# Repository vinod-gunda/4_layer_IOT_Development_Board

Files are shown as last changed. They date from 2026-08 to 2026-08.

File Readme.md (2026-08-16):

# 4-Layer ESP32-C3 Development Board

A custom **4-layer ESP32-C3 development board** designed from scratch using **KiCad 10** as part of my embedded systems and PCB design learning.

## Key Features

- ESP32-C3 based controller
- USB-C, USB-UART, Li-Po charging and power management
- SD Card, Flash Memory and sensor interfaces
- 4-layer PCB with power and GND distribution

## PCB Design Skills

- Custom schematic symbol design
- Custom footprint design
- Custom logo-to-footprint conversion
- Hierarchical schematic design
- PCB layout, routing and DRC verification

## Tools & Technology

- **KiCad 10**
- **ESP32-C3**
- **4-Layer PCB**

## Repository Contents

- KiCad schematic files
- PCB layout files
- Custom symbols and footprints
- Project images

## Purpose

This project was developed for **learning, prototyping, and improving practical PCB design skills**.

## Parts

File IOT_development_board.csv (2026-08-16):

Reference | Qty | Value | DNP | Exclude from BOM | Exclude from Board | Footprint | Datasheet
C1 | 1 | 0.1u |  |  |  | Capacitor_SMD:C_0805_2012Metric
C2,C5,C8,C10,C13,C14,C15,C16,C18,C20,C21 | 11 | 0.1uF |  |  |  | Capacitor_SMD:C_0805_2012Metric
C3,C4 | 2 | 10uF |  |  |  | TANTALUM-SMD-10UF-20V-20__1206:CT1206
C6 | 1 | 1u |  |  |  | Capacitor_SMD:C_0805_2012Metric
C7,C12 | 2 | 10uf |  |  |  | TANTALUM-SMD-10UF-20V-20__1206:CT1206
C9 | 1 | 4.7uF |  |  |  | TANTALUM-SMD-10UF-20V-20__1206:CT1206
C11,C19,C22 | 3 | 1uF |  |  |  | Capacitor_SMD:C_0805_2012Metric
C17 | 1 | 10nF |  |  |  | Capacitor_SMD:C_0805_2012Metric
D1,D5 | 2 | LTST-C170GKT |  |  |  | LTST-C170GKT:LED_LTST-C170GKT
D2,D4,D6 | 3 | LTST-C170KRKT |  |  |  | LTST-C170KRKT:DIOC200X125X110
D3 | 1 | LTST-C170TBKT |  |  |  | LTST-C170TBKT:DIOC200X125X110
F1 | 1 | 0ZCH0110AF2E |  |  |  | 0ZCH0110AF2E:FUSC3225X100N
J1 | 1 | SS-52400-003 |  |  |  | C_TYPE:BELFUSE_SS-52400-003
J2 | 1 | B2B-PH-SM4-TB |  |  |  | B2B-PH-SM4-TB:JST_B2B-PH-SM4-TB
J3 | 1 | GSD090012SEU |  |  |  | GSD090012SEU:AMPHENOL_GSD090012SEU
J4 | 1 | Conn_01x04_Pin |  |  |  | Connector_PinHeader_2.54mm:PinHeader_1x04_P2.54mm_Vertical
J5 | 1 | Conn_01x05_Pin |  |  |  | Connector_PinHeader_2.54mm:PinHeader_1x05_P2.54mm_Vertical
MK1 | 1 | CMC-5042PF-AC |  |  |  | CMC-5042PF-AC:CUI_CMC-5042PF-AC
Q1 | 1 | TEMT6000X01 |  |  |  | TEMT6000X01:TRANS_TEMT6000X01
Q2,Q3 | 2 | BC817 |  |  |  | Package_TO_SOT_SMD:SOT-23 | https://www.onsemi.com/pub/Collateral/BC818-D.pdf
R1,R2,R19,R23,R30,R32,R33,R34 | 8 | 10K |  |  |  | Resistor_SMD:R_0805_2012Metric
R3,R4 | 2 | 5.1K |  |  |  | Resistor_SMD:R_0805_2012Metric
R5,R26,R28 | 3 | 2K |  |  |  | Resistor_SMD:R_0805_2012Metric
R6 | 1 | 20K |  |  |  | Resistor_SMD:R_0805_2012Metric
R7,R8,R9,R10,R14,R15 | 6 | 470 |  |  |  | Resistor_SMD:R_0805_2012Metric
R11 | 1 | 1K |  |  |  | Resistor_SMD:R_0805_2012Metric
R12 | 1 | 22.1K |  |  |  | Resistor_SMD:R_0805_2012Metric
R13 | 1 | 47.5K |  |  |  | Resistor_SMD:R_0805_2012Metric
R16,R20,R21,R22 | 4 | 50 |  |  |  | Resistor_SMD:R_0805_2012Metric
R24,R25 | 2 | 4.7K |  |  |  | Resistor_SMD:R_0805_2012Metric
R27,R29 | 2 | 1M |  |  |  | Resistor_SMD:R_0805_2012Metric
R31 | 1 | 100K |  |  |  | Resistor_SMD:R_0805_2012Metric
S1 | 1 | BOOT |  |  |  | USLPT2819DT2TR:SW_USLPT2819DT2TR
S2 | 1 | RESET |  |  |  | USLPT2819DT2TR:SW_USLPT2819DT2TR
TP1 | 1 | MOSI |  |  |  | TestPoint:TestPoint_Pad_D1.0mm
TP2 | 1 | MISO |  |  |  | TestPoint:TestPoint_Pad_D1.0mm
TP3 | 1 | SCLK |  |  |  | TestPoint:TestPoint_Pad_D1.0mm
TP4 | 1 | CS_SD |  |  |  | TestPoint:TestPoint_Pad_D1.0mm
TP5 | 1 | CS |  |  |  | TestPoint:TestPoint_Pad_D1.0mm
U1 | 1 | MCP73871 |  |  |  | Package_DFN_QFN:QFN-20-1EP_4x4mm_P0.5mm_EP2.5x2.5mm | http://www.mouser.com/ds/2/268/22090a-52174.pdf
U2 | 1 | BME280 |  |  |  | BME280:PSON65P250X250X100-8N
U3 | 1 | ESP32-C3-WROOM-02-H4 |  |  |  | ESP32-C3-WROOM-02-H4:MODULE_ESP32-C3-WROOM-02-H4
U4 | 1 | CP2102N-A02-GQFN20R |  |  |  | CP2102N-A02-GQFN20R:SILABS_CP2102N-A02-GQFN20R
U5 | 1 | USBLC6-2SC6 |  |  |  | Package_TO_SOT_SMD:SOT-23-6 | https://www.st.com/resource/en/datasheet/usblc6-2.pdf
U6 | 1 | W25Q32JVSSIQ |  |  |  | W25Q32JVSSIQ:SOIC127P790X216-8N
U7 | 1 | MAX4466EXK |  |  |  | MAX4466EXK:SOT65P210X110-5N
VR1 | 1 | LM1117MPX-3.3 |  |  |  | LM1117MPX-3.3:VREG_LM1117MPX-3.3

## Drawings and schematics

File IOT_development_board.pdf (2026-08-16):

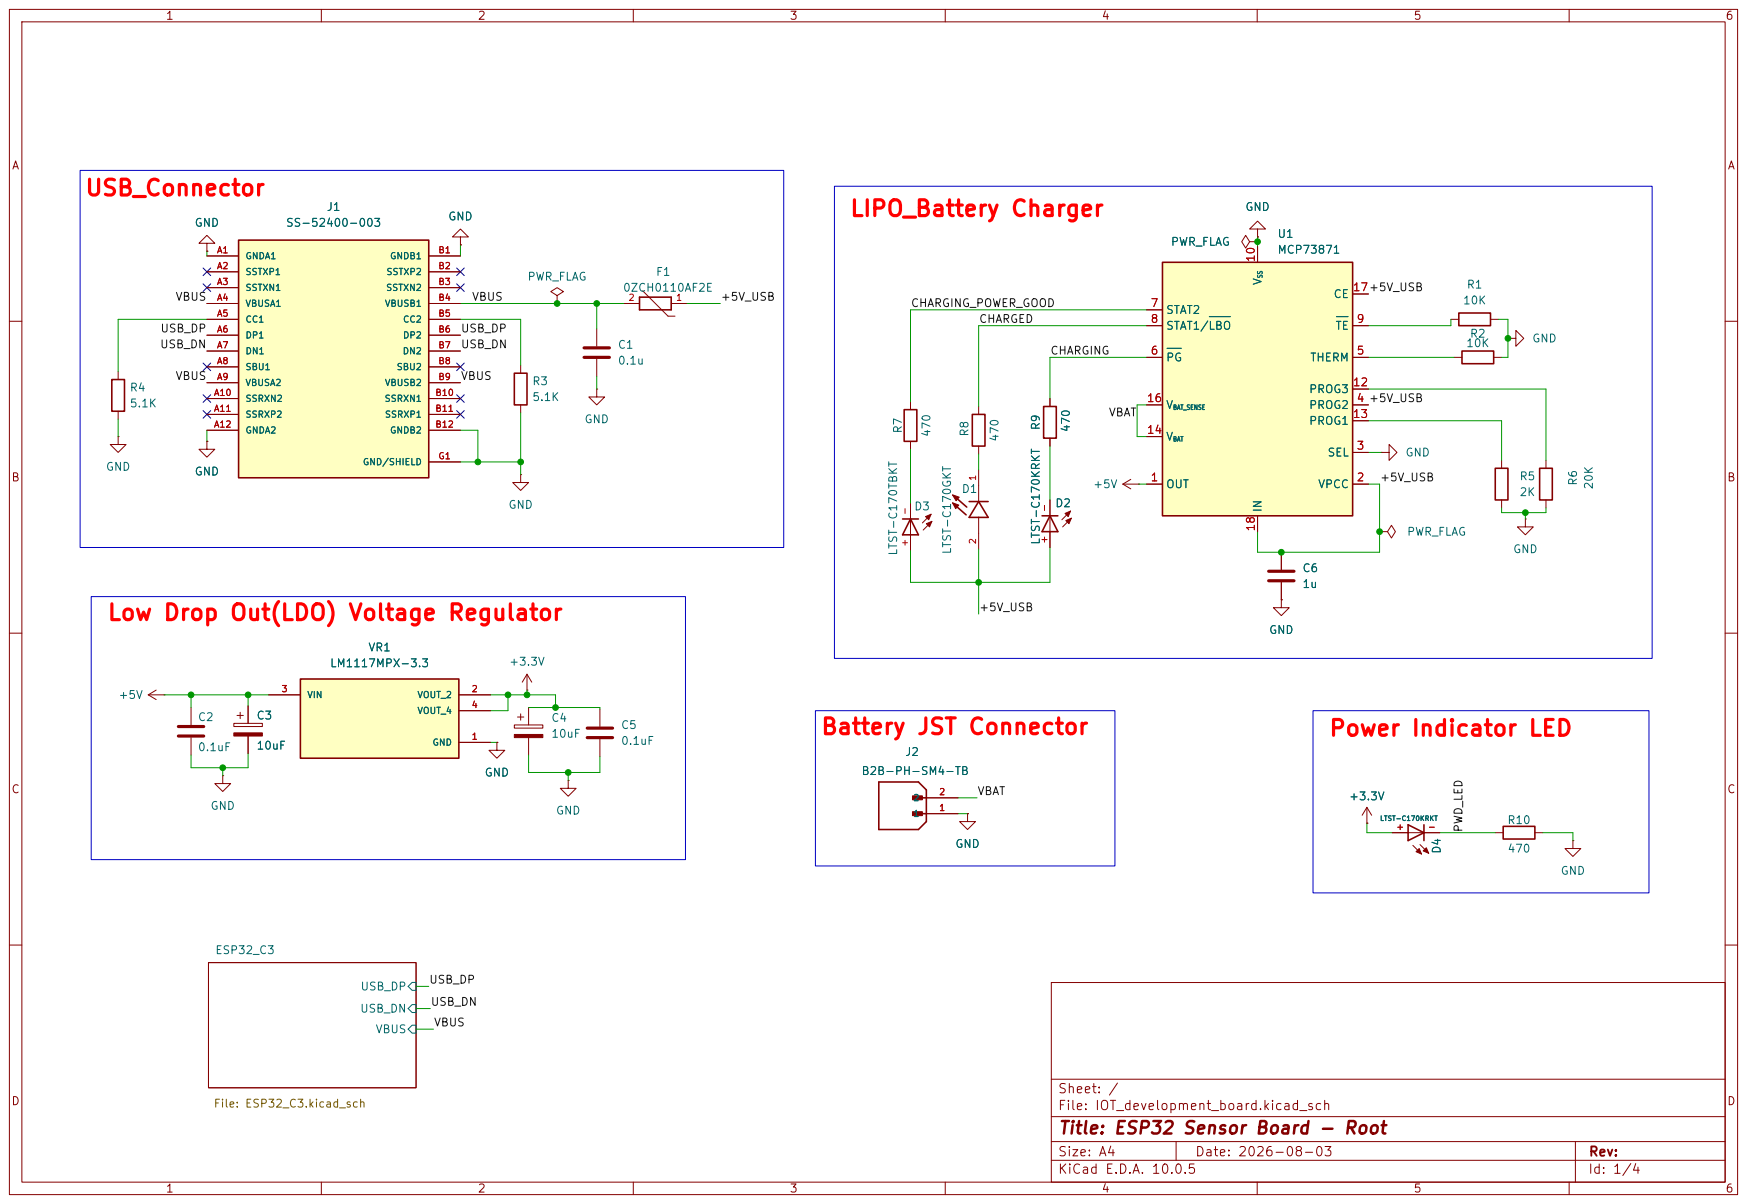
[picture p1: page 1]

Low Drop Out(LDO) Voltage Regulator

Sheet: /
File: IOT_development_board.kicad_sch
Title: ESP32 Sensor Board - Root

Size: A4 | Rev:
KiCad E.D.A. 10.0.5 | Id: 1/4

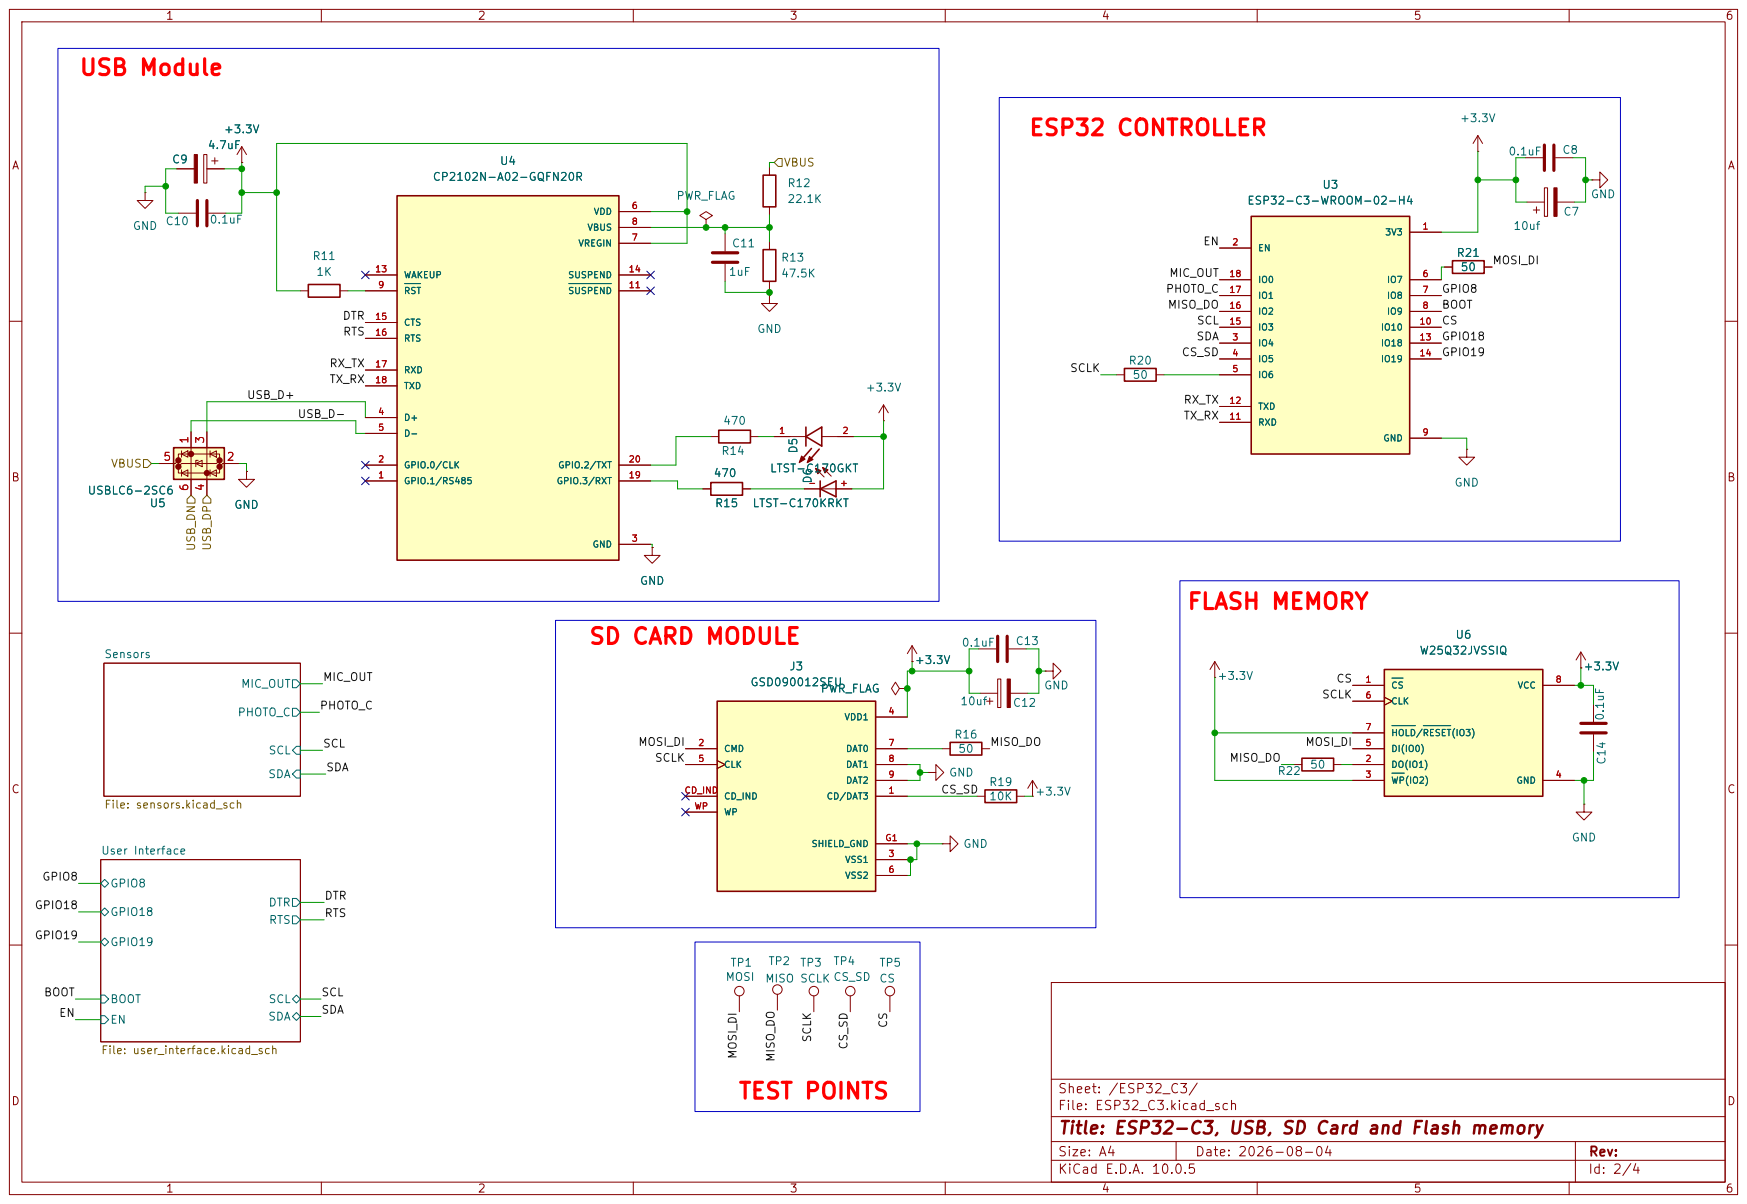
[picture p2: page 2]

SCL SDA User Interface

Sheet: /ESP32_C3/
File: ESP32_C3.kicad_sch
Title: ESP32-C3, USB, SD Card and Flash memory

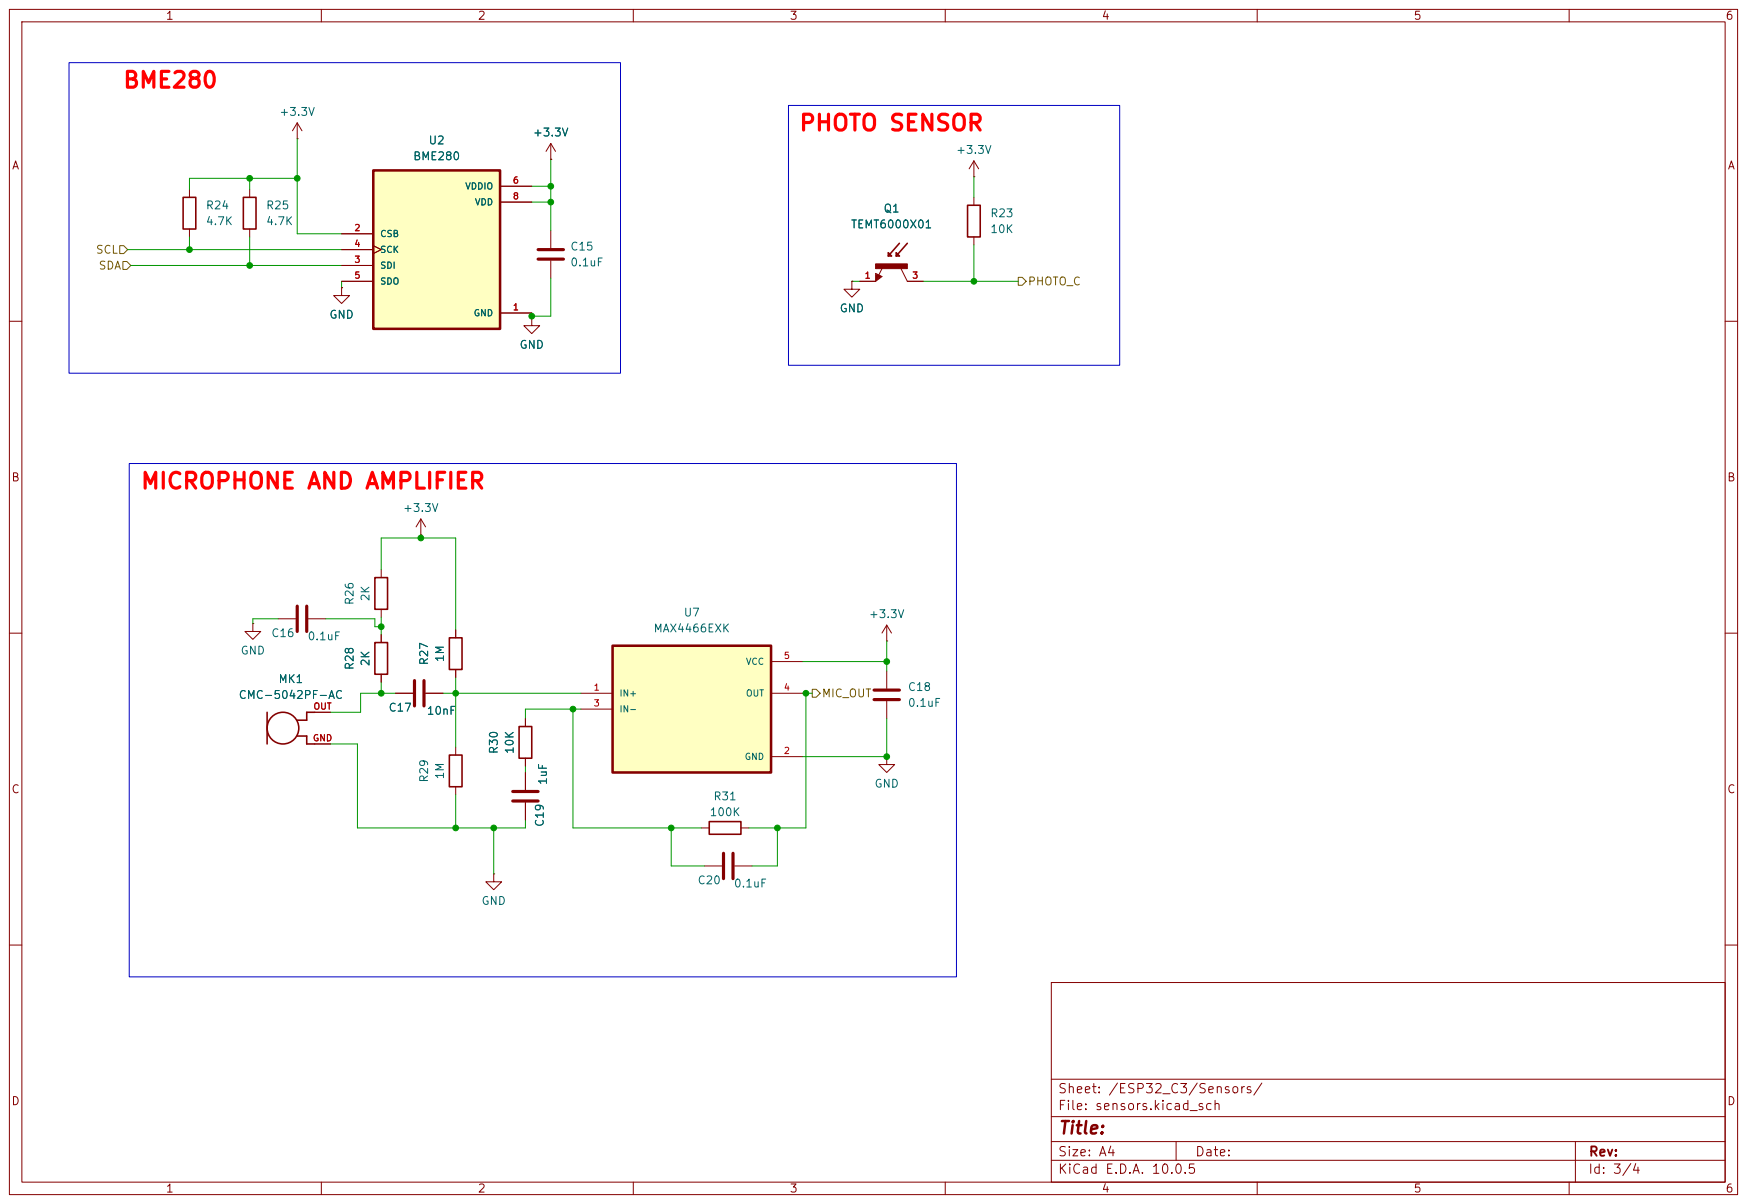
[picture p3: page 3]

GND OUT MK1 CMC-5042PF-AC R26 2K

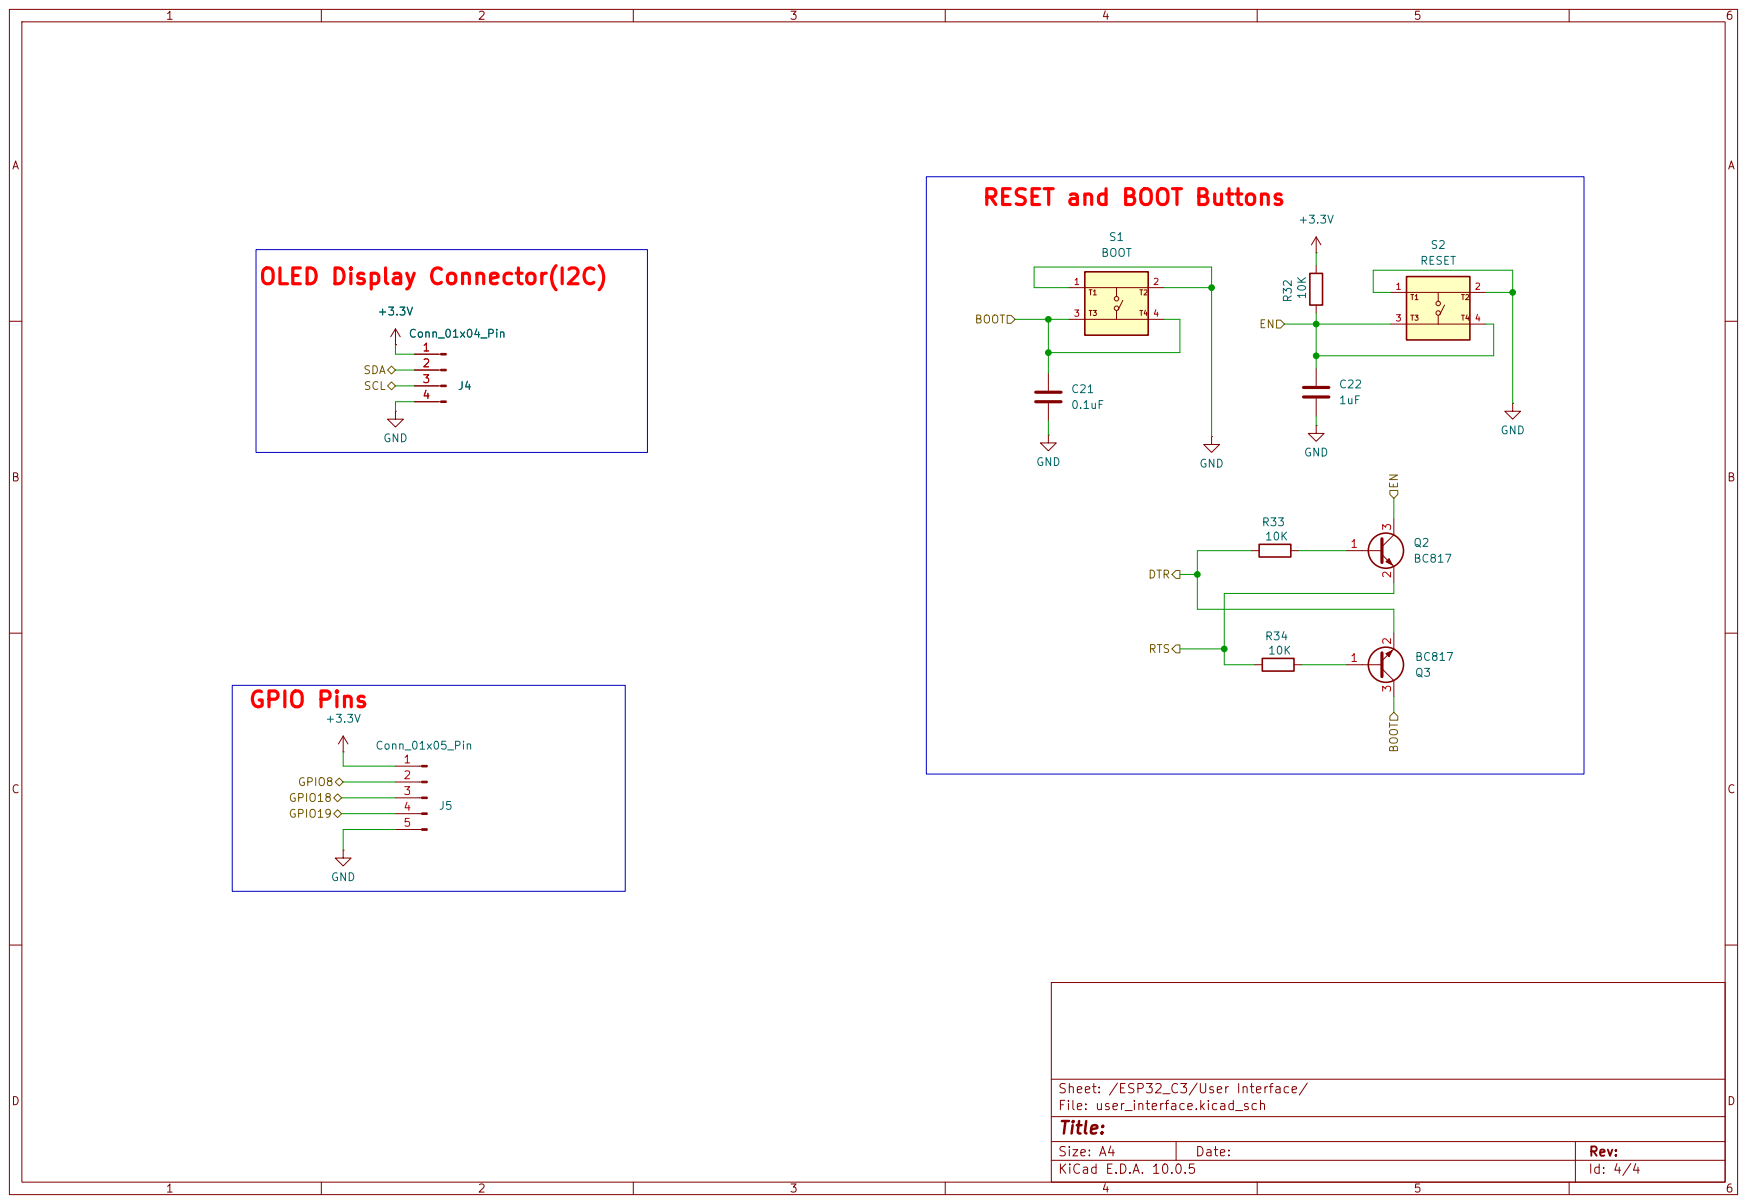
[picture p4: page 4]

EN RESET and BOOT Buttons

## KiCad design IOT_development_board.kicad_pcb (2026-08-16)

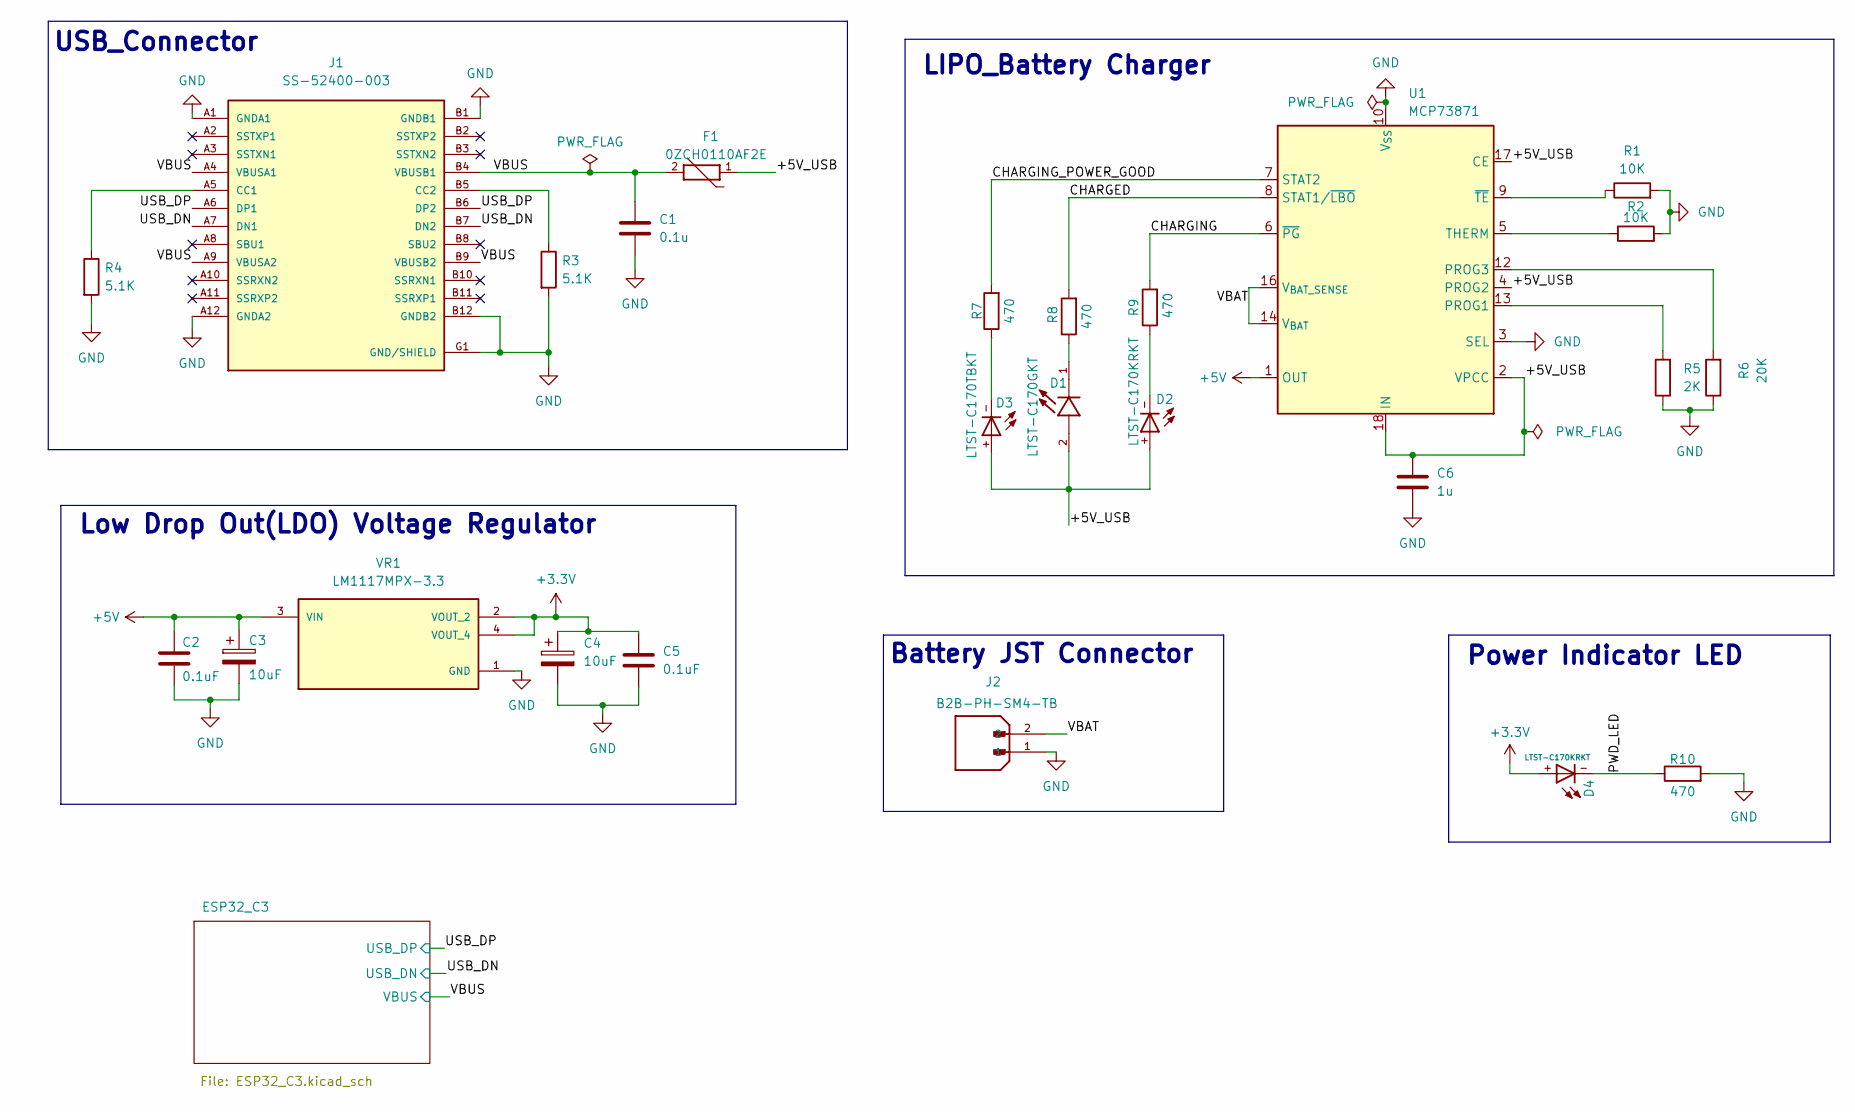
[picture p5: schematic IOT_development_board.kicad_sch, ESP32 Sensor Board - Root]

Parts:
C1: 0.1u; C_0805_2012Metric
C2, C5: 0.1uF; C_0805_2012Metric
C3, C4: 10uF; CT1206
C6: 1u; C_0805_2012Metric
D1: LTST-C170GKT; LED_LTST-C170GKT; PARTREV I
D2, D4: LTST-C170KRKT; DIOC200X125X110
D3: LTST-C170TBKT; DIOC200X125X110
F1: 0ZCH0110AF2E; FUSC3225X100N; PARTREV Apr2023
J1: SS-52400-003; BELFUSE_SS-52400-003; PARTREV A0
J2: B2B-PH-SM4-TB; JST_B2B-PH-SM4-TB; PARTREV N/A
R1, R2: 10K; R_0805_2012Metric
R3, R4: 5.1K; R_0805_2012Metric
R5: 2K; R_0805_2012Metric
R6: 20K; R_0805_2012Metric
R7, R8, R9, R10: 470; R_0805_2012Metric
U1: MCP73871; QFN-20-1EP_4x4mm_P0.5mm_EP2.5x2.5mm
VR1: LM1117MPX-3.3; VREG_LM1117MPX-3.3; PARTREV O

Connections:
+3.3V: C4.1, C5.1, D4.+, VR1.2 (VOUT_2), VR1.4 (VOUT_4); also elsewhere on the board
+5V: C2.1, C3.1, U1.1 (OUT), U1.20 (OUT), VR1.3 (VIN)
/+5V_USB: C6.1, D1.2, D2.+, D3.+, F1.1, U1.2 (VPCC), U1.4 (PROG2), U1.17 (CE), U1.18 (IN), U1.19 (IN)
/CHARGED: R8.2, U1.8 (STAT1/~LBO)
/CHARGING: R9.2, U1.6 (~PG)
/CHARGING_POWER_GOOD: R7.2, U1.7 (STAT2)
/PWD_LED: D4.-, R10.1
/USB_DN: J1.A7 (DN1), J1.B7 (DN2); also elsewhere on the board
/USB_DP: J1.A6 (DP1), J1.B6 (DP2); also elsewhere on the board
/VBAT: J2.2, U1.14 (V_{BAT}), U1.15 (V_{BAT}), U1.16 (V_{BAT_SENSE})
/VBUS: C1.1, F1.2, J1.A4 (VBUSA1), J1.A9 (VBUSA2), J1.B4 (VBUSB1), J1.B9 (VBUSB2); also elsewhere on the board
GND: C1.2, C2.2, C3.2, C4.2, C5.2, C6.2, J1.A1 (GNDA1), J1.A12 (GNDA2), J1.B1 (GNDB1), J1.B12 (GNDB2), J1.G1 (GND/SHIELD), J1.G2 (GND/SHIELD), J1.G3 (GND/SHIELD), J1.G4 (GND/SHIELD), J1.S1 (GND/SHIELD), J1.S2 (GND/SHIELD), J1.S3 (GND/SHIELD), J1.S4 (GND/SHIELD), J2.1, R1.2, R2.2, R3.2, R4.2, R5.1, R6.1, R10.2, U1.3 (SEL), U1.10 (V_{SS}), U1.11 (V_{SS}), U1.21 (V_{SS}), VR1.1 (GND); also elsewhere on the board
unnamed: D1.1, R8.1
unnamed: D2.-, R9.1
unnamed: D3.-, R7.1
unnamed: J1.A5 (CC1), R4.1
unnamed: J1.B5 (CC2), R3.1
unnamed: R5.2, U1.13 (PROG1)
unnamed: R6.2, U1.12 (PROG3)
unnamed: R2.1, U1.5 (THERM)
unnamed: R1.1, U1.9 (~TE)

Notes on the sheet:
LIPO_Battery Charger
Battery JST Connector
Power Indicator LED
Low Drop Out(LDO) Voltage Regulator
USB_Connector

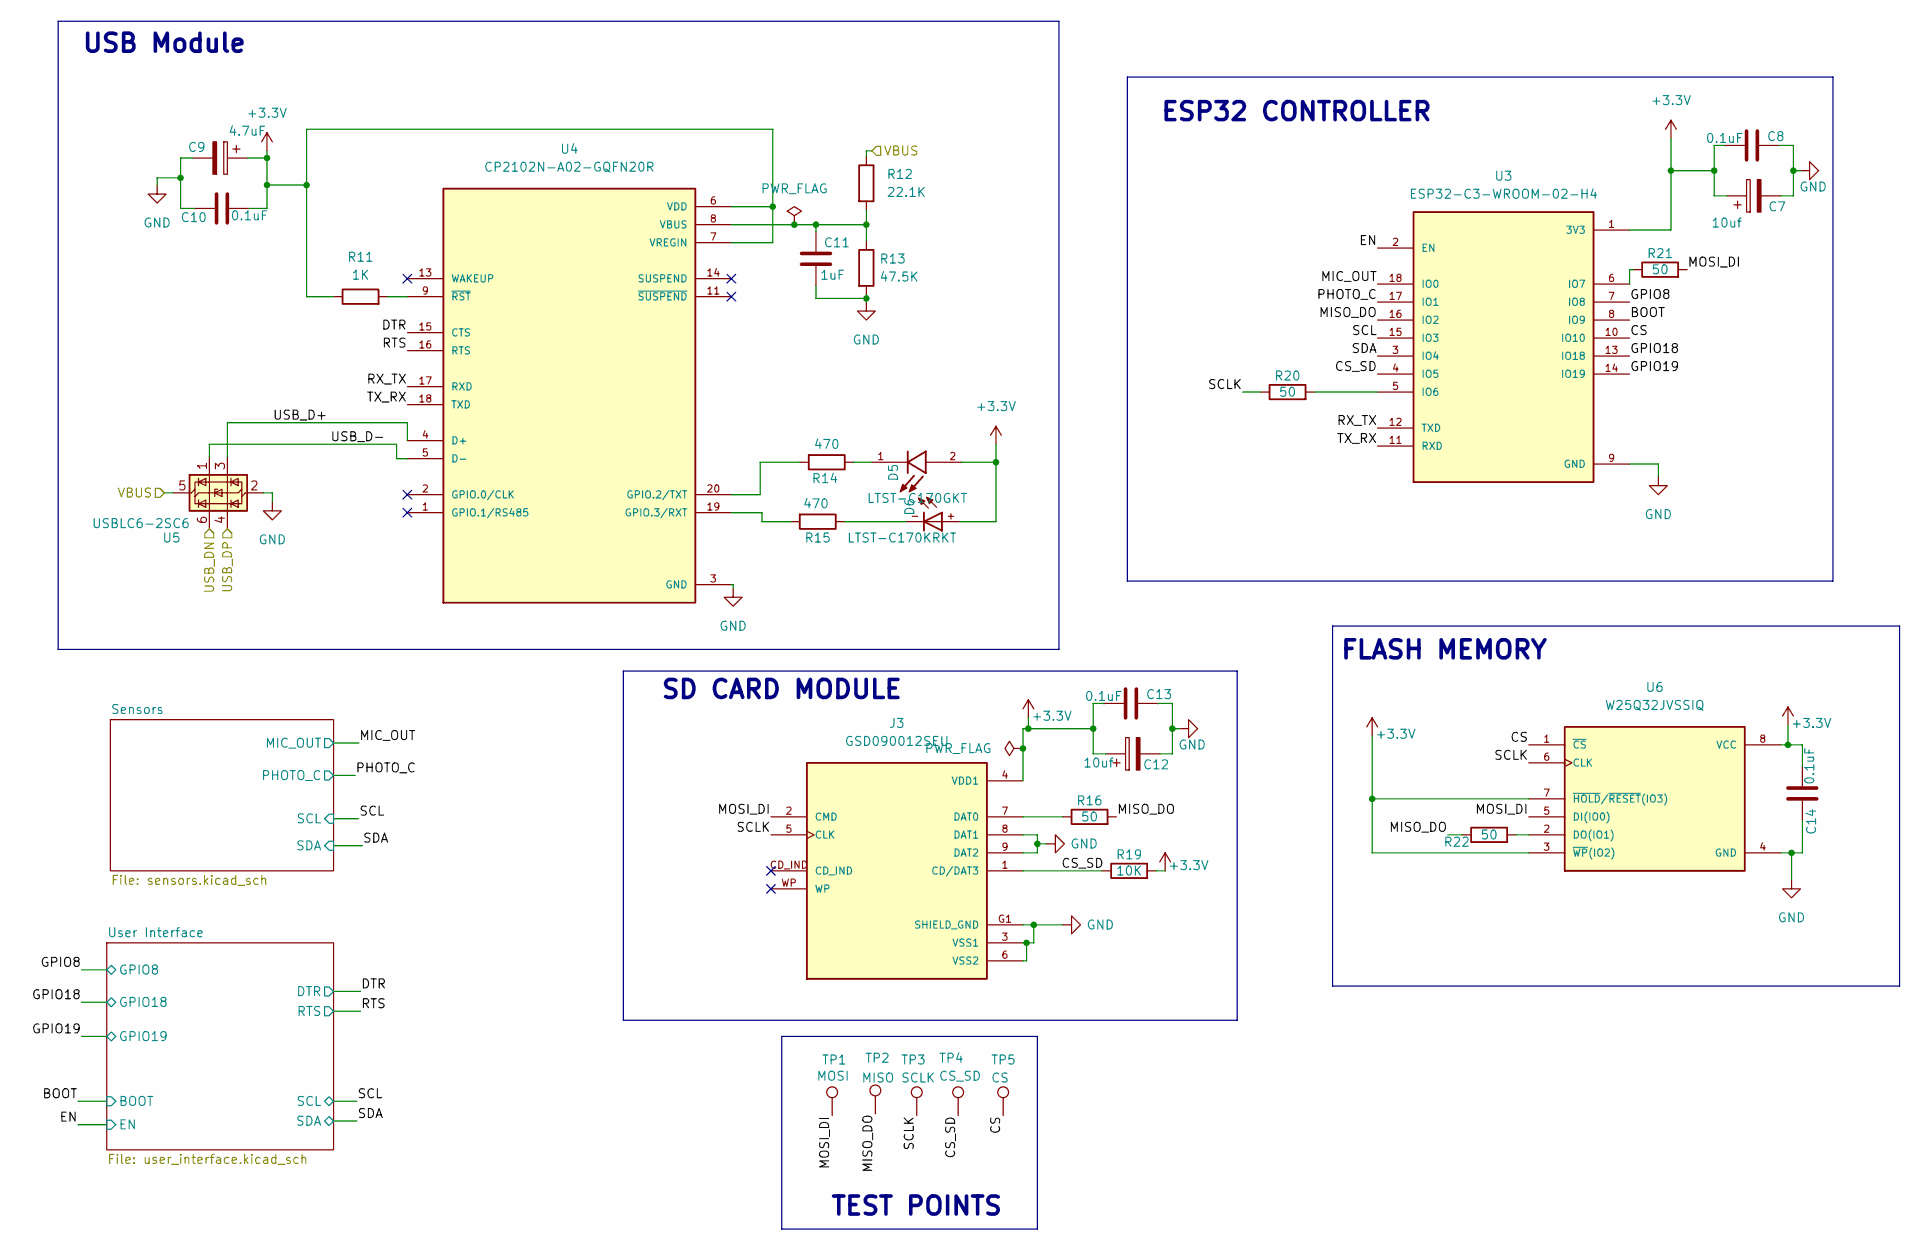
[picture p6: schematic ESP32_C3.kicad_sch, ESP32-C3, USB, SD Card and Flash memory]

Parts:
C7, C12: 10uf; CT1206
C8, C10, C13, C14: 0.1uF; C_0805_2012Metric
C9: 4.7uF; CT1206
C11: 1uF; C_0805_2012Metric
D5: LTST-C170GKT; LED_LTST-C170GKT; PARTREV I
D6: LTST-C170KRKT; DIOC200X125X110
J3: GSD090012SEU; AMPHENOL_GSD090012SEU; PARTREV E
R11: 1K; R_0805_2012Metric
R12: 22.1K; R_0805_2012Metric
R13: 47.5K; R_0805_2012Metric
R14, R15: 470; R_0805_2012Metric
R16, R20, R21, R22: 50; R_0805_2012Metric
R19: 10K; R_0805_2012Metric
TP1: MOSI; TestPoint_Pad_D1.0mm
TP2: MISO; TestPoint_Pad_D1.0mm
TP3: SCLK; TestPoint_Pad_D1.0mm
TP4: CS_SD; TestPoint_Pad_D1.0mm
TP5: CS; TestPoint_Pad_D1.0mm
U3: ESP32-C3-WROOM-02-H4; MODULE_ESP32-C3-WROOM-02-H4
U4: CP2102N-A02-GQFN20R; SILABS_CP2102N-A02-GQFN20R; PARTREV 1.3
U5: USBLC6-2SC6; SOT-23-6
U6: W25Q32JVSSIQ; SOIC127P790X216-8N; M_PART_NUMBER W25QXX

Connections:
+3.3V: C7.1, C8.2, C9.1, C10.2, C12.1, C13.2, C14.2, D5.2, D6.+, J3.4 (VDD1), R11.1, R19.2, U3.1 (3V3), U4.6 (VDD), U4.7 (VREGIN), U6.3 (~WP(IO2)), U6.7 (~HOLD/~RESET(IO3)), U6.8 (VCC); also elsewhere on the board
/ESP32_C3/CS: TP5.1 (1_1), U3.10 (IO10), U6.1 (~CS)
/ESP32_C3/EN: U3.2 (EN); also elsewhere on the board
/ESP32_C3/GPIO8: U3.7 (IO8); also elsewhere on the board
/ESP32_C3/GPIO18: U3.13 (IO18); also elsewhere on the board
/ESP32_C3/GPIO19: U3.14 (IO19); also elsewhere on the board
/ESP32_C3/MISO_DO: R16.2, R22.1, TP2.1 (1_1), U3.16 (IO2)
/ESP32_C3/MOSI_DI: J3.2 (CMD), R21.2, TP1.1 (1_1), U6.5 (DI(IO0))
/ESP32_C3/PHOTO_C: U3.17 (IO1); also elsewhere on the board
/ESP32_C3/RTS: U4.16 (RTS); also elsewhere on the board
/ESP32_C3/RX_TX: U3.12 (TXD), U4.17 (RXD)
/ESP32_C3/SCL: U3.15 (IO3); also elsewhere on the board
/ESP32_C3/SCLK: J3.5 (CLK), R20.1, TP3.1 (1_1), U6.6 (CLK)
/ESP32_C3/SDA: U3.3 (IO4); also elsewhere on the board
/ESP32_C3/TX_RX: U3.11 (RXD), U4.18 (TXD)
/ESP32_C3/USB_D+: U4.4 (D+), U5.3 (I/O2)
/ESP32_C3/USB_D-: U4.5 (D-), U5.1 (I/O1)
/USB_DN: U5.6 (I/O1); also elsewhere on the board
/USB_DP: U5.4 (I/O2); also elsewhere on the board
/VBUS: R12.1, U5.5 (VBUS); also elsewhere on the board
GND: C7.2, C8.1, C9.2, C10.1, C11.2, C12.2, C13.1, C14.1, J3.3 (VSS1), J3.6 (VSS2), J3.8 (DAT1), J3.9 (DAT2), J3.G1 (SHIELD_GND), J3.G2 (SHIELD_GND), J3.G3 (SHIELD_GND), J3.G4 (SHIELD_GND), R13.2, U3.9 (GND), U3.19 (GND), U3.20 (GND), U3.21 (GND), U3.22 (GND), U3.23 (GND), U3.24 (GND), U3.25 (GND), U3.26 (GND), U3.27 (GND), U3.28 (GND), U3.29 (GND), U3.30 (GND), U3.31 (GND), U3.32 (GND), U3.33 (GND), U3.34 (GND), U3.35 (GND), U3.36 (GND), U3.37 (GND), U3.38 (GND), U3.39 (GND), U4.3 (GND), U4.12 (GND), U4.21 (GND), U5.2 (GND), U6.4 (GND); also elsewhere on the board
unnamed: D5.1, R14.1
unnamed: D6.-, R15.1
unnamed: J3.7 (DAT0), R16.1
unnamed: R20.2, U3.5 (IO6)
unnamed: R21.1, U3.6 (IO7)
unnamed: R14.2, U4.20 (GPIO.2/TXT)
unnamed: R15.2, U4.19 (GPIO.3/RXT)
unnamed: C11.1, R12.2, R13.1, U4.8 (VBUS)
unnamed: R11.2, U4.9 (~RST)
unnamed: R22.2, U6.2 (DO(IO1))

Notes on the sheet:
TEST POINTS
FLASH MEMORY
ESP32 CONTROLLER
SD CARD MODULE
USB Module

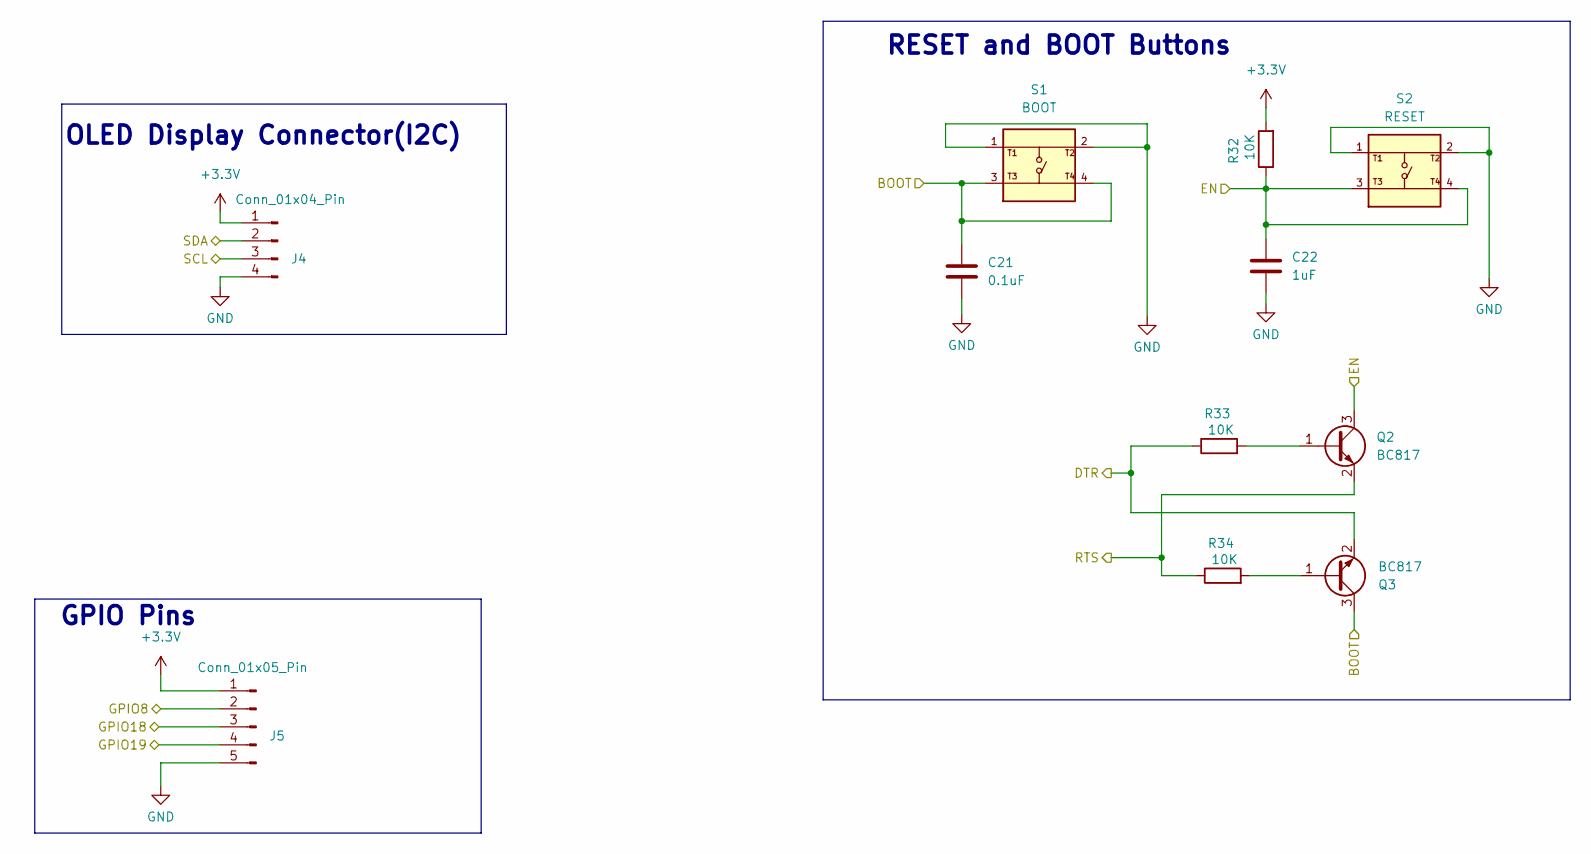
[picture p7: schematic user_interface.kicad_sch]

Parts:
C21: 0.1uF; C_0805_2012Metric
C22: 1uF; C_0805_2012Metric
J4: Conn_01x04_Pin; PinHeader_1x04_P2.54mm_Vertical
J5: Conn_01x05_Pin; PinHeader_1x05_P2.54mm_Vertical
Q2, Q3: BC817; SOT-23
R32, R33, R34: 10K; R_0805_2012Metric
S1: BOOT; SW_USLPT2819DT2TR; PARTREV P
S2: RESET; SW_USLPT2819DT2TR; PARTREV P

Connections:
+3.3V: J4.1, J5.1, R32.2; also elsewhere on the board
/ESP32_C3/EN: C22.1, Q2.3 (C), R32.1, S2.3, S2.4; also elsewhere on the board
/ESP32_C3/GPIO8: J5.2; also elsewhere on the board
/ESP32_C3/GPIO18: J5.3; also elsewhere on the board
/ESP32_C3/GPIO19: J5.4; also elsewhere on the board
/ESP32_C3/RTS: Q2.2 (E), R34.1; also elsewhere on the board
/ESP32_C3/SCL: J4.3; also elsewhere on the board
/ESP32_C3/SDA: J4.2; also elsewhere on the board
GND: C21.2, C22.2, J4.4, J5.5, S1.1, S1.2, S2.1, S2.2; also elsewhere on the board
unnamed: Q2.1 (B), R33.2
unnamed: Q3.1 (B), R34.2

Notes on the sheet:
OLED Display Connector(I2C)
RESET and BOOT Buttons
GPIO Pins

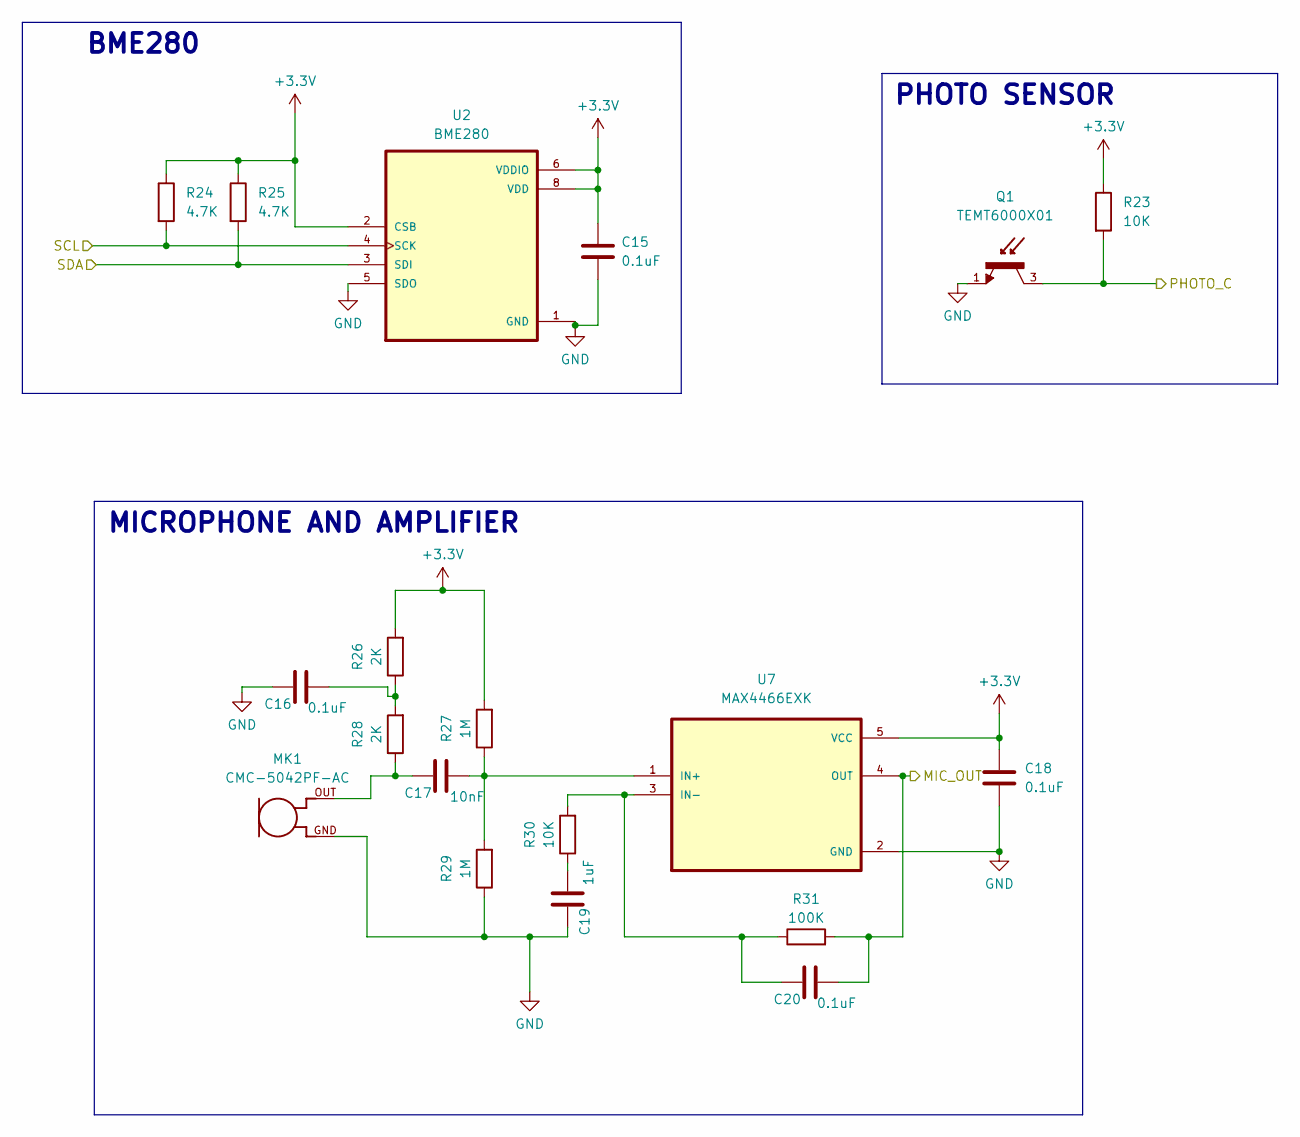
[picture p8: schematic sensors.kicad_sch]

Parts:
C15, C16, C18, C20: 0.1uF; C_0805_2012Metric
C17: 10nF; C_0805_2012Metric
C19: 1uF; C_0805_2012Metric
MK1: CMC-5042PF-AC; CUI_CMC-5042PF-AC
Q1: TEMT6000X01; TRANS_TEMT6000X01; PARTREV 1.9
R23, R30: 10K; R_0805_2012Metric
R24, R25: 4.7K; R_0805_2012Metric
R26, R28: 2K; R_0805_2012Metric
R27, R29: 1M; R_0805_2012Metric
R31: 100K; R_0805_2012Metric
U2: BME280; PSON65P250X250X100-8N
U7: MAX4466EXK; SOT65P210X110-5N

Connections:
+3.3V: C15.1, C18.1, R23.1, R24.1, R25.1, R26.2, R27.2, U2.2 (CSB), U2.6 (VDDIO), U2.8 (VDD), U7.5 (VCC); also elsewhere on the board
/ESP32_C3/PHOTO_C: Q1.3, R23.2; also elsewhere on the board
/ESP32_C3/SCL: R24.2, U2.4 (SCK); also elsewhere on the board
/ESP32_C3/SDA: R25.2, U2.3 (SDI); also elsewhere on the board
GND: C15.2, C16.1, C18.2, C19.1, MK1.GND, Q1.1, R29.1, U2.1 (GND), U2.5 (SDO), U2.7 (GND), U7.2 (GND); also elsewhere on the board
unnamed: C16.2, R26.1, R28.2
unnamed: C17.1, MK1.OUT, R28.1
unnamed: C19.2, R30.1
unnamed: C17.2, R27.1, R29.2, U7.1 (IN+)
unnamed: C20.1, R30.2, R31.1, U7.3 (IN-)

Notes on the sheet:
BME280
MICROPHONE AND AMPLIFIER
PHOTO SENSOR

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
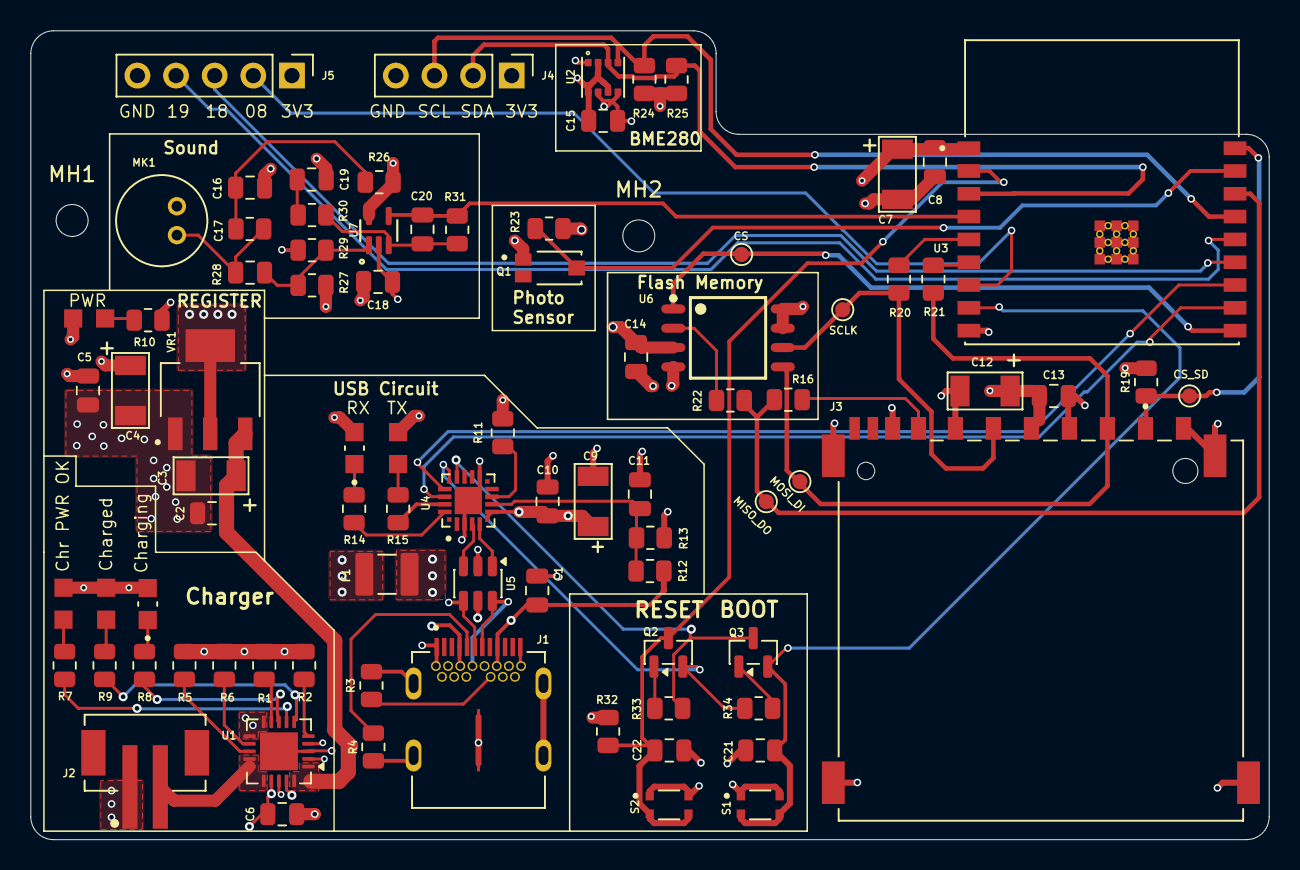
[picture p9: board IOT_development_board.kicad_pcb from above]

Board: 4 copper layers, 81.4 x 53.2 mm, 87 parts (0 on the bottom side), 58 nets.

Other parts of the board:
MH1, MH2: MountingHole_2.1mm
